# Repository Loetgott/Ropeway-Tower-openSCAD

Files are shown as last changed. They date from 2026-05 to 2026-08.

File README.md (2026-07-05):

# 🚠 Ropeway Tower OpenSCAD (3S Seilbahn Stütze)

A fully parametric OpenSCAD project for generating a model ropeway tower (specifically designed for 3S aerial tramways).

This project allows you to customize and generate 3D printable STL files of a ropeway tower for your model ropeway setups.



## ✨ Features

- **Fully Parametric:** Adjust the tower's height, number of floors, angles, and rod diameters to fit your specific needs.
- **Customizable Details:** Toggle the rendering of structural rods and construction helpers.
- **3D Printing Ready:** Easily export the generated models as STL files for your 3D printer. (A pre-rendered `stütze.stl` is included in the repository).
- **JSON Parameter Support:** Comes with a preset `stütze.json` file for easy parameter management in the OpenSCAD Customizer.

## 🛠️ Requirements

- [OpenSCAD](https://openscad.org/downloads.html) (Version 2021.01 or newer recommended)

## 🚀 Usage

1. Clone or download this repository.
2. Open the `stütze.scad` file in OpenSCAD.
3. Use the **Customizer** panel in OpenSCAD (if hidden, enable it via *Window -> Customizer*) to load the `stütze.json` preset or modify the parameters manually.
4. Adjust the parameters to your liking (see the Parameters section below).
5. Press `F5` to preview your changes.
6. Press `F6` to render the final geometry.
7. Click on *File -> Export -> Export as STL* to save your model for 3D printing.

## ⚙️ Parameters

You can adjust these variables directly in the OpenSCAD customizer or at the top of the `stütze.scad` file:

| Parameter | Description | Default Preset |
| :--- | :--- | :--- |
| `height` | The total height of the tower structure. | `600` |
| `angle` | The main inclination angle of the tower framework. | `15` |
| `angle_on_top` | The angle of the top saddle structure. | `51` |
| `floor_count` | Number of intermediate floors/cross-sections. | `3` |
| `big_rod_diameter` | Diameter of the primary vertical and horizontal structural rods. | `5` |
| `small_rod_diameter` | Diameter of the secondary diagonal supporting rods. | `3` |
| `draw_rods` | Toggle to render the threaded rods (`true`/`false`). | `true` |
| `draw_construction_helpers`| Toggle to show construction vectors and points (useful for debugging). | `false` |

## 📸 Media / More Info

For more pictures, videos, and updates about model ropeway projects, check out the Instagram page:

👉 **[@seilbahn_modellbau](https://www.instagram.com/seilbahn_modellbau/)**

## 📝 License

Feel free to modify, print, and share your creations for your model ropeways!

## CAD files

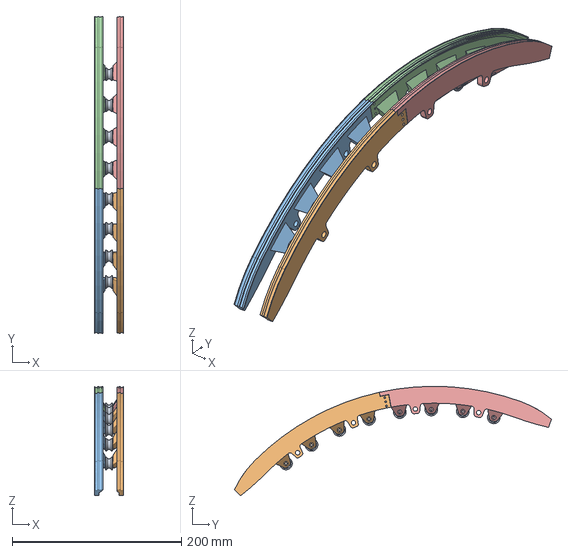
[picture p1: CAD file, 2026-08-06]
Stützenschuhe.step
34.0 x 374.7 x 129.3 mm

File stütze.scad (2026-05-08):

height = 600;
angle = 15;
angle_on_top = 51;
floor_count = 3;
draw_construction_helpers = false;
draw_rods = true;

big_rod_diameter = 5;
small_rod_diameter = 3;

function dot(a, b) = a[0] * b[0] + a[1] * b[1] + a[2] * b[2];

// gibt den Schnittpunkt eines Vektors mit der xy-Ebene zurück
function intersect_with_xy(p,
                           v) = p + v * (-p.z / v.z); // Skaliere v, damit z=0

// gibt eine Liste von regelmäßig verteilten Punkten auf einem Vektor zurück
function subdivide(p_top, p_bottom, n) = [for (i = [1:n - 1]) p_top +
                                          (p_bottom - p_top) * (i / n)];

// Gibt den Mittelpunkt zwischen zwei Punkten zurück
function midpoint(p1, p2) =
    [ (p1[0] + p2[0]) / 2, (p1[1] + p2[1]) / 2, (p1[2] + p2[2]) / 2 ];

function rotate_vec(v, axis, angle) =
    v * cos(angle) +
    cross(axis, v) * sin(angle) + axis * dot(axis, v) * (1 - cos(angle));

function normalize(v) = v / norm(v);

function angle_between(a, b) = acos(dot(a, b) / (norm(a) * norm(b)));

function angle_between_normal(v1, v2, normal) = 
    atan2(
        (cross(v1, v2) * normal), // Determinante / Richtung
        (v1 * v2)                 // Skalarprodukt
    );

dir = [ 0, height* sin(angle), height* cos(angle) ];
top_point = dir; // punkt oben in der Mitte
cross_to_edge = cross([ 50, 0, 0 ], dir);
vec_to_corner = [ 50, 0, 0 ] + ((cross_to_edge / norm(cross_to_edge)) * 38);

a = top_point + vec_to_corner;
b = top_point + [ -vec_to_corner.x, vec_to_corner.y, vec_to_corner.z ];
c = top_point + [ -vec_to_corner.x, -vec_to_corner.y, -vec_to_corner.z ];
d = top_point + [ vec_to_corner.x, -vec_to_corner.y, -vec_to_corner.z ];

a_on_top = a + normalize(dir) * 90;
b_on_top = b + normalize(dir) * 90;
c_on_top = c + normalize(dir) * 90;
d_on_top = d + normalize(dir) * 90;

a_to_front = rotate_vec(dir, [ 1, 0, 0 ], angle_on_top);
b_to_front = rotate_vec(dir, [ 1, 0, 0 ], angle_on_top);
c_to_front = rotate_vec(dir, [ 1, 0, 0 ], -angle_on_top);
d_to_front = rotate_vec(dir, [ 1, 0, 0 ], -angle_on_top);

ground_vec_y = cross_to_edge / norm(cross_to_edge) * height * tan(11.6);
ground_vec_x = [ 1, 0, 0 ] * height * tan(6.3);

a_to_ground = -dir + ground_vec_y + ground_vec_x;
b_to_ground = -dir + ground_vec_y - ground_vec_x;
c_to_ground = -dir - ground_vec_y - ground_vec_x;
d_to_ground = -dir - ground_vec_y + ground_vec_x;

a_on_ground = intersect_with_xy(a, a_to_ground);
b_on_ground = intersect_with_xy(b, b_to_ground);
c_on_ground = intersect_with_xy(c, c_to_ground);
d_on_ground = intersect_with_xy(d, d_to_ground);

floor_height = norm((c_on_ground - c) / floor_count);

subdivide_c_list = subdivide(c, c_on_ground, floor_count);
subdivide_d_list = subdivide(d, d_on_ground, floor_count);

points_on_a_to_ground = [
    a,
    for (i = [1:floor_count - 1]) a +
        (a_to_ground / norm(a_to_ground) * i * floor_height),
    a_on_ground
];
points_on_b_to_ground = [
    b,
    for (i = [1:floor_count - 1]) b +
        (b_to_ground / norm(b_to_ground) * i * floor_height),
    b_on_ground
];
points_on_c_to_ground = [
    c,
    for (i = [0:len(subdivide_c_list) - 1]) subdivide_c_list[i],
    c_on_ground
];
points_on_d_to_ground = [
    d,
    for (i = [0:len(subdivide_d_list) - 1]) subdivide_d_list[i],
    d_on_ground
];

middle_points_on_a_to_ground = [
    for (i = [1:floor_count - 1]) a +
        (a_to_ground / norm(a_to_ground) * i * floor_height) -
        0.5 * a_to_ground / norm(a_to_ground) * floor_height,
    a_on_ground
];
middle_points_on_b_to_ground = [
    for (i = [1:floor_count - 1]) b +
        (b_to_ground / norm(b_to_ground) * i * floor_height) -
        0.5 * b_to_ground / norm(b_to_ground) * floor_height,
    b_on_ground
];
middle_points_on_c_to_ground = [
    for (i = [1:floor_count - 1]) c +
        (c_to_ground / norm(c_to_ground) * i * floor_height) -
        0.5 * c_to_ground / norm(c_to_ground) * floor_height,
    c_on_ground
];
middle_points_on_d_to_ground = [
    for (i = [1:floor_count - 1]) d +
        (d_to_ground / norm(d_to_ground) * i * floor_height) -
        0.5 * d_to_ground / norm(d_to_ground) * floor_height,
    d_on_ground
];

middle_points_a_b = [for (i = [0:floor_count - 1])
        midpoint(points_on_a_to_ground[i], points_on_b_to_ground[i])];
middle_points_b_c = [for (i = [0:floor_count - 1])
        midpoint(points_on_b_to_ground[i], points_on_c_to_ground[i])];
middle_points_c_d = [for (i = [0:floor_count - 1])
        midpoint(points_on_c_to_ground[i], points_on_d_to_ground[i])];
middle_points_d_a = [for (i = [0:floor_count - 1])
        midpoint(points_on_d_to_ground[i], points_on_a_to_ground[i])];

if (draw_construction_helpers) { // show construction helping vectors
    color("red")
    {
        cylinder_from_point([ 0, 0, 0 ], dir, height, 2.5); // height cylinder
        for (p = [ a, b, c, d ]) {
            cylinder_between(top_point, p, 2.5); // cross for a,b,c,d
        }

        // Alle Punkt-Arrays, zusammengefasst mit gewünschtem Radius
        point_groups = [[points_on_a_to_ground, 8],
                        [points_on_b_to_ground, 8],
                        [points_on_c_to_ground, 8],
                        [points_on_d_to_ground, 8],
                        [middle_points_on_a_to_ground, 6],
                        [middle_points_on_b_to_ground, 6],
                        [middle_points_on_c_to_ground, 6],
                        [middle_points_on_d_to_ground, 6],
                        [middle_points_a_b, 6],
                        [middle_points_b_c, 6],
                        [middle_points_c_d, 6],
                        [middle_points_d_a, 6]];

        // Schleife über die Gruppen
        for (grp = point_groups) {
            points = grp[0];
            r = grp[1];
            for (p = points)
                translate(p) sphere(r = r);
        }
    }
}

if (draw_rods) {
    color("blue")
    {
        threaded_rods();
    }
}

color("green")
{
    // top layer connector
    top_connector_side();
    sub_top_connector_side();
    mirror([ 1, 0, 0 ])
    {
        top_connector_side();
        sub_top_connector_side();
    }

    top_connector_front();
    sub_top_connector_front();
    mirror(cross(dir, [ 1, 0, 0 ]))
    {
        top_connector_front();
        sub_top_connector_front();
    }
    
    ground_connector_a(b_on_ground,
                     b_to_ground,
                     middle_points_b_c[len(middle_points_b_c) - 1],
                     middle_points_a_b[len(middle_points_a_b) - 1]);
    mirror([1, 0, 0]){
        ground_connector_a(b_on_ground,
                     b_to_ground,
                     middle_points_b_c[len(middle_points_b_c) - 1],
                     middle_points_a_b[len(middle_points_a_b) - 1]);
                     }
    ground_connector_b(c_on_ground,
                     c_to_ground,
                     middle_points_b_c[len(middle_points_b_c) - 1],
                     middle_points_c_d[len(middle_points_c_d) - 1]);
                     
     mirror([1, 0, 0])
         ground_connector_b(c_on_ground,
                     c_to_ground,
                     middle_points_b_c[len(middle_points_b_c) - 1],
                     middle_points_c_d[len(middle_points_c_d) - 1]);

    // Main connectors
    for (i = [1:floor_count - 1]) {
        main_connector_a(
            points_on_a_to_ground[i], a_to_ground, points_on_d_to_ground[i]);

        mirror([ 1, 0, 0 ]) main_connector_a(
            points_on_a_to_ground[i], a_to_ground, points_on_d_to_ground[i]);

        mirror(cross(dir, [ 1, 0, 0 ])) main_connector_a(
            points_on_a_to_ground[i], a_to_ground, points_on_d_to_ground[i]);

        mirror([ 1, 0, 0 ]) mirror(cross(dir, [ 1, 0, 0 ])) main_connector_a(
            points_on_a_to_ground[i], a_to_ground, points_on_d_to_ground[i]);
    }

    // vertical middle conectors
    for (i = [0:floor_count - 2]) {
        vertical_middle_connector(middle_points_on_a_to_ground[i],
                                  a_to_ground,
                                  middle_points_a_b[i],
                                  middle_points_a_b[i + 1],
                                  middle_points_d_a[i],
                                  middle_points_d_a[i + 1]);
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

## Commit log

2026-01-03 added scad file
    [stütze.scad]
2026-01-03 Update stütze.scad
    vectors for the sides
    [stütze.scad]
2026-01-04 new openscad version
    update to newer openscad version
    [stütze.scad]
2026-01-05 floor points correctly calculated
    [stütze.scad]
2026-01-05 all bars now calculated
    [stütze.scad]
2026-01-06 basic structure with connectors finished
    [stütze.scad]
2026-01-06 renamed one param
    [stütze.scad]
2026-01-08 first prism for stronger connectros
    [stütze.scad]
2026-01-10 main connectors finished
    [stütze.scad]
2026-01-10 updated main connectors & begin of bottom connectors
    [stütze.scad]
2026-01-10 added mor module for more connectors
    [stütze.scad]
2026-01-11 little bugfix
    [stütze.scad]
2026-01-26 added vertical middle connectors
    [stütze.scad]
2026-01-26 beginning upper floor
    [stütze.scad]
2026-01-26 added stabilizer on top
    [stütze.scad]
2026-01-31 added more stabilizer triangles
    [stütze.scad]
2026-03-06 dings
    dings
    [stütze.scad]
2026-03-07 beginning of ground supports
    [stütze.scad]
2026-03-07 half of the ground connectors are right now
    [stütze.scad]
2026-03-07 all ground connectors are correct
    [stütze.scad]
2026-03-08 added console log for threaded rods lenghts
    [stütze.scad]
2026-03-08 added the ground coordinates
    [stütze.scad]
2026-03-09 top front connectors finished
    [stütze.scad]
2026-03-14 correct hole diameters on main connectors
    [stütze.scad]
2026-03-14 added new threaded ros in the upper level
    [stütze.scad]
2026-03-29 finished the top front connectors
    [stütze.scad]
2026-03-30 top side connectors version 1 finished
    [stütze.scad]
2026-04-09 added some holes to the side top connectors
    [stütze.scad]
2026-05-08 new straight floor on top for more clearance between cabin and support tower
    [stütze.scad]
2026-08-06 added the upper support bodys
    [Stützenschuhe.step]
